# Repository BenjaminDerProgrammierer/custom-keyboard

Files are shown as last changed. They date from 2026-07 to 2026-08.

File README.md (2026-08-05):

# Custom keyboard

My try on a custom keyboard. I've always wanted to design a bigger PCB and case, and Keeb was the perfect opportunity. My challenge is a near-ISO keyboard layout.

## TODO

* what you built, why, and what you learned
* Add Rotary Encoder and OLED display ("Extras")

## Attribution

Thanks to [Hack Club Keeb](https://keeb.hackclub.com/) for encouraging me to build my own keyboard.

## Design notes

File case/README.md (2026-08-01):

# Onshape project export directory

[View my onshape project here](https://cad.onshape.com/documents/79eabb8dc9f468c958f379de/w/43301b686be9b350d744fb77/e/7cf8c5e329865d698f6473ac).

Alternatively, you can use the exported files in this directory.

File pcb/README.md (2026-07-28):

# KiCAD project directory

## Adding gerbers

* Go to File → Fabrication Outputs → Gerbers (.gbr)
* Select all layers (F.Cu, B.Cu, F.Silkscreen, B.Silkscreen, F.Mask, B.Mask, Edge.Cuts) and click Plot
* Then click Generate Drill Files to export the .drl file
* Zip the output folder and commit it alongside your .kicad_pcb and .kicad_sch files

## Layout

For viewing the source layout, upload `layout.json` to <https://www.keyboard-layout-editor.com/>

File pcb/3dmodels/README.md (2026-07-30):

# PCB 3D models

These models are kept with the project so `${KIPRJMOD}` references in
`custom_keyboard.kicad_pcb` do not depend on a particular workstation.

| Project file | Source |
| --- | --- |
| `Cherry_MX.step` | Existing local project asset, formerly referenced as `Cherry MX.STEP` |
| `D_DO-35_SOD27_P7.62mm_Horizontal.step` | [KiCad Packages3D](https://gitlab.com/kicad/libraries/kicad-packages3D/-/raw/master/Diode_THT.3dshapes/D_DO-35_SOD27_P7.62mm_Horizontal.step) |
| `RaspberryPi_Pico.step` | [KiCad Packages3D](https://gitlab.com/kicad/libraries/kicad-packages3D/-/raw/master/Module.3dshapes/RaspberryPi_Pico.step) |
| `Stabilizer-2u.stp` | [Keychron L1 2.25u stabilizer](http://www.keychron.co:34568/keychron-github-assets/Keychron-Keyboards-Hardware-Design/L-Series/L1/Stabilizer-2.25u.stp) |
| `Stabilizer-6.25u.stp` | [Keychron L1 6.25u stabilizer](http://www.keychron.co:34568/keychron-github-assets/Keychron-Keyboards-Hardware-Design/L-Series/L1/Stabilizer-6.25u.stp) |
| `Stabilizer_5u.wrl` | Project-local, footprint-aligned horizontal 5u stabilizer representation |
| `Stabilizer_ISO.wrl` | Project-local, footprint-aligned vertical ISO stabilizer representation |
| `Keycap_1u_Transparent.wrl` | Project-local generic transparent keycap shell |
| `Keycap_ISO_Transparent.wrl` | Project-local transparent ISO Enter shell |

The standard 2.25u stabilizer assembly is also used for the 2u and 2.75u
footprints because they share the same 23.8125 mm stem spacing. ISO Enter uses
a project-local vertical representation aligned directly to its four mounting
holes.

Refer to the upstream projects for their model licensing terms.

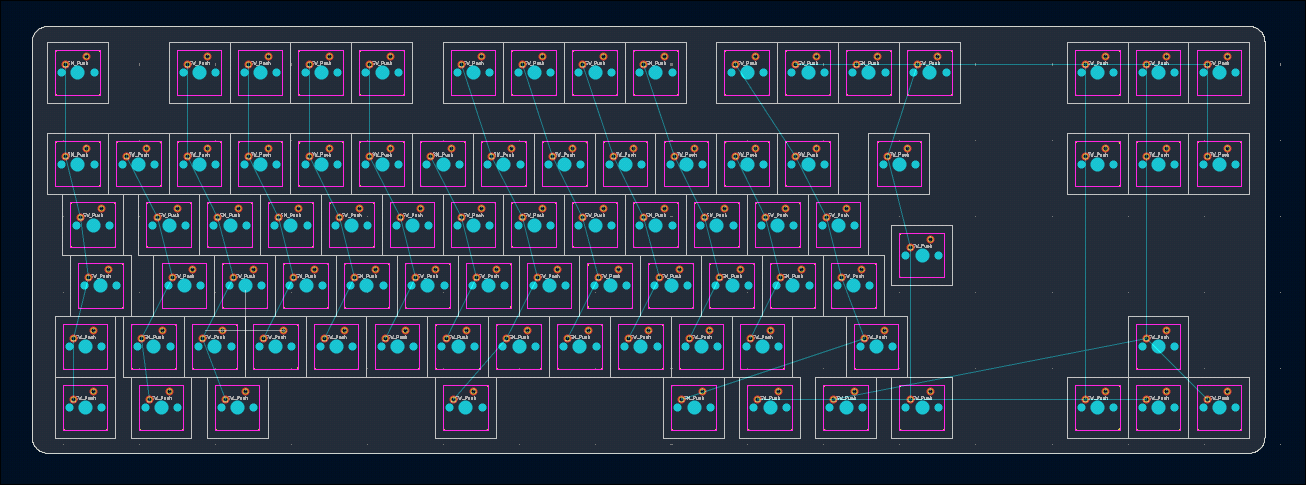
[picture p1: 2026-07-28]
assets/screenshot-003.png

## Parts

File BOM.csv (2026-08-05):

Part | Quantity | PackQuantity | PriceUSD | Link | Notes
Raspberry Pi Pico | 1 | 1 | 9.34 | https://amzn.eu/d/05j1KStX
1N4148 Diode | 87 | 100 | 5.81 | https://amzn.eu/d/0eLkkfi4
EC11 Rotary Encoder | 1 | 10 | 12.33 | https://amzn.eu/d/0akEk5m6
0.91" OLED Display | 1 | 1 | 6.7 | https://amzn.eu/d/095Z39cg
PCB | 1 | 5 | 47.17 |  | JLCPCB see submission/pcb_order.png
MX Switch | 86 | 90 | 51.23 | https://amzn.eu/d/0a2MXvMT
MX Stabilizers | 6 | 8 | 13.07 | https://amzn.eu/d/04WCo8ej
TOTAL |  |  | 145.65

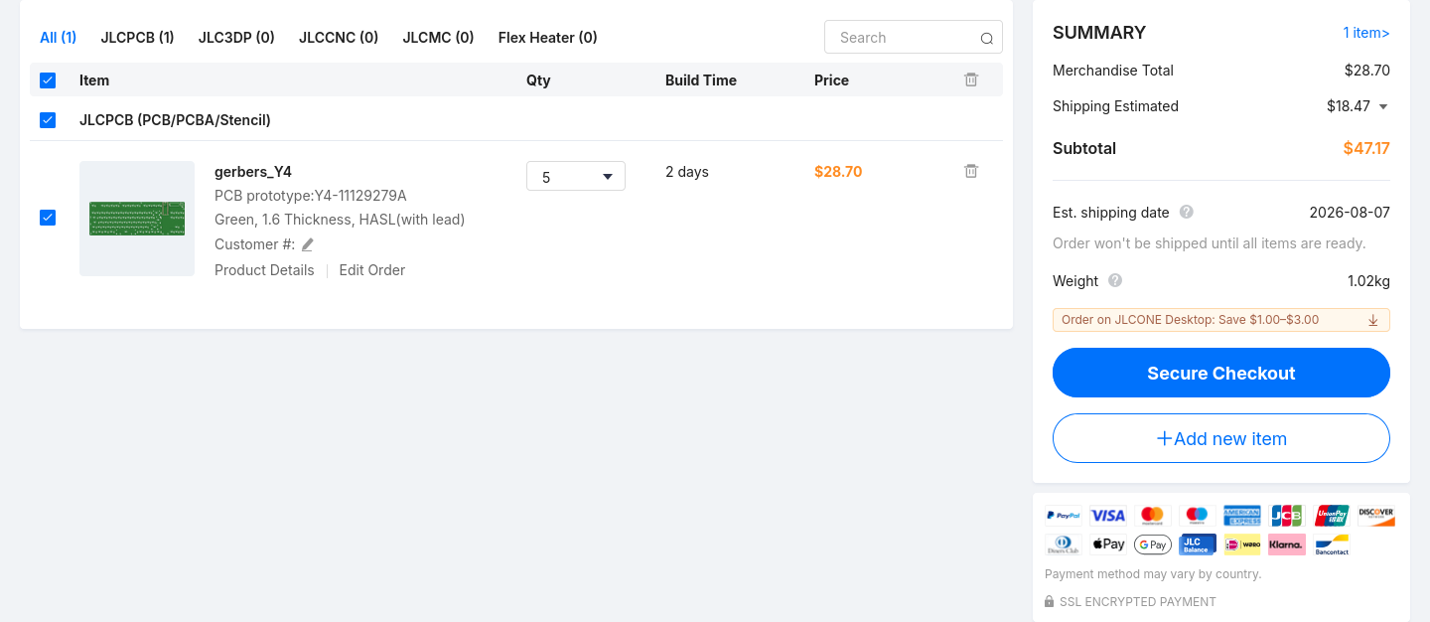
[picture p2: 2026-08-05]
submission/pcb_order.png

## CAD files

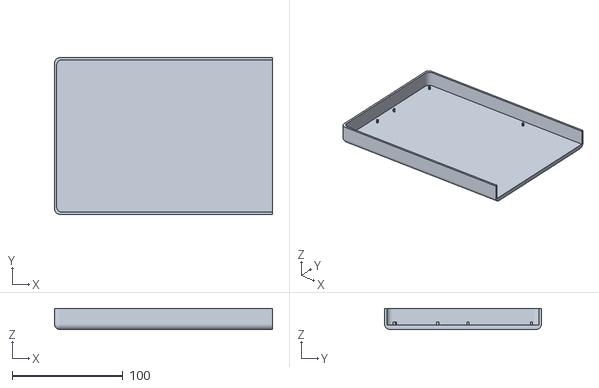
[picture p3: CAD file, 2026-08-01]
case/case - part 1.stl
197.0 x 141.7 x 19.0

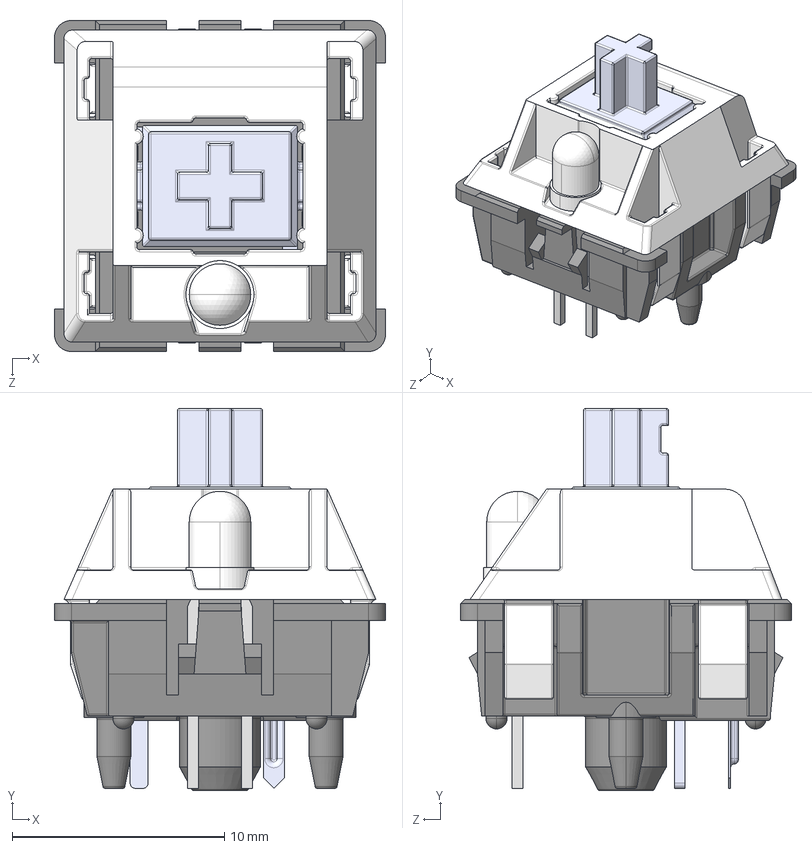
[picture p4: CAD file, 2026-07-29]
pcb/3dmodels/Cherry_MX.step
15.6 x 18.0 x 15.6 mm
Bottom
Pulsador
Top
Pieza5^Cherry MX
Pin1
Pin2
Led 3mm_trans

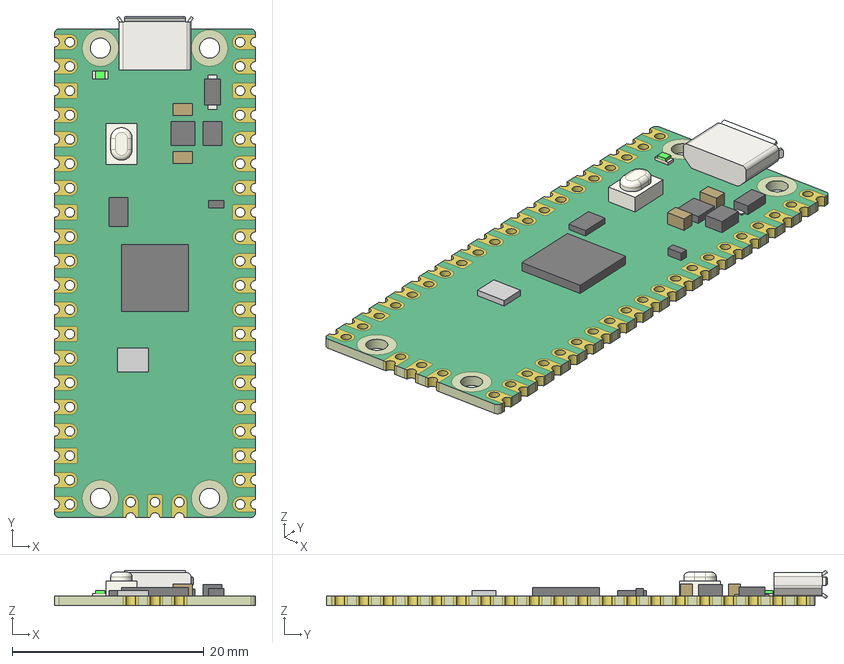
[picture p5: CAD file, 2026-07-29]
pcb/3dmodels/RaspberryPi_Pico.step
21.0 x 52.3 x 3.70 mm

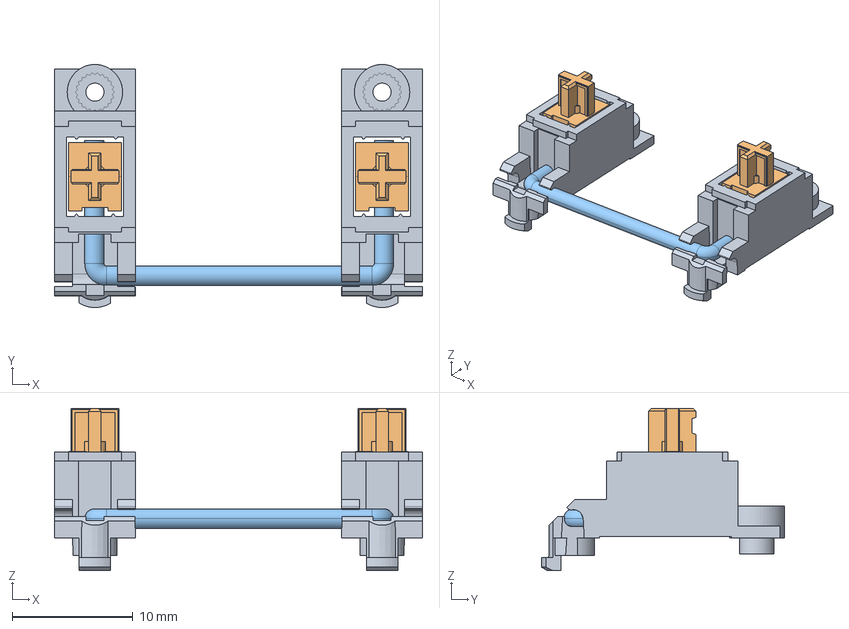
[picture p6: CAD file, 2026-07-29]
pcb/3dmodels/Stabilizer-2u.stp
30.5 x 20.1 x 13.5 mm
WX_Z_4__1_1_25 x 2
D_1_25 x 2
PINGHENGGAN_1_25

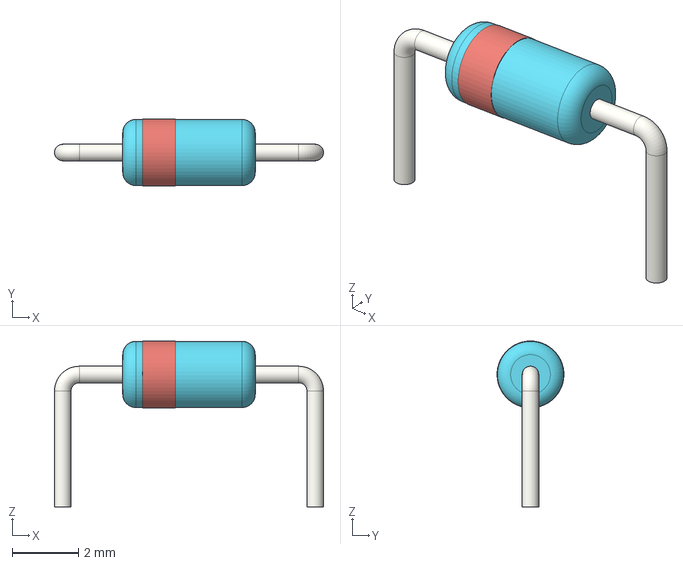
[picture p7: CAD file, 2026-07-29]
pcb/3dmodels/D_DO-35_SOD27_P7.62mm_Horizontal.step
8.12 x 2.02 x 5.01 mm

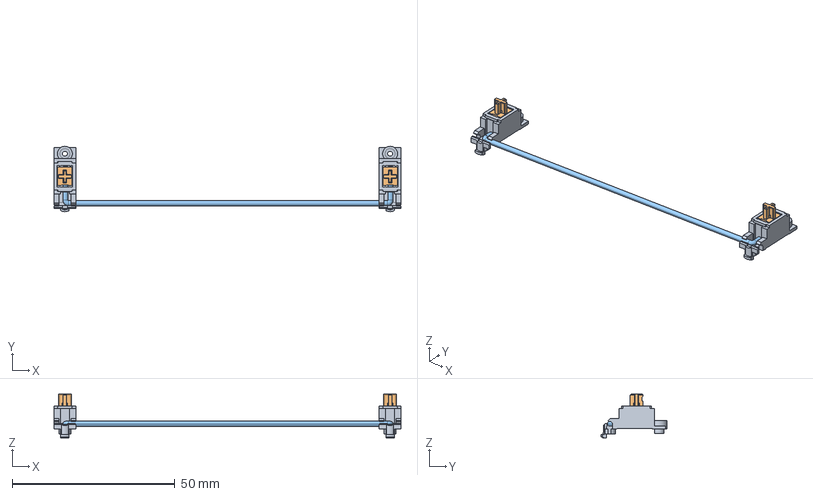
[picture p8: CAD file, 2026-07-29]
pcb/3dmodels/Stabilizer-6.25u.stp
106.7 x 20.1 x 13.5 mm
WX_Z_4__1_1_25 x 2
D_1_25 x 2
PINGHENGGAN100_25

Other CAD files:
case/case - part 2.stl

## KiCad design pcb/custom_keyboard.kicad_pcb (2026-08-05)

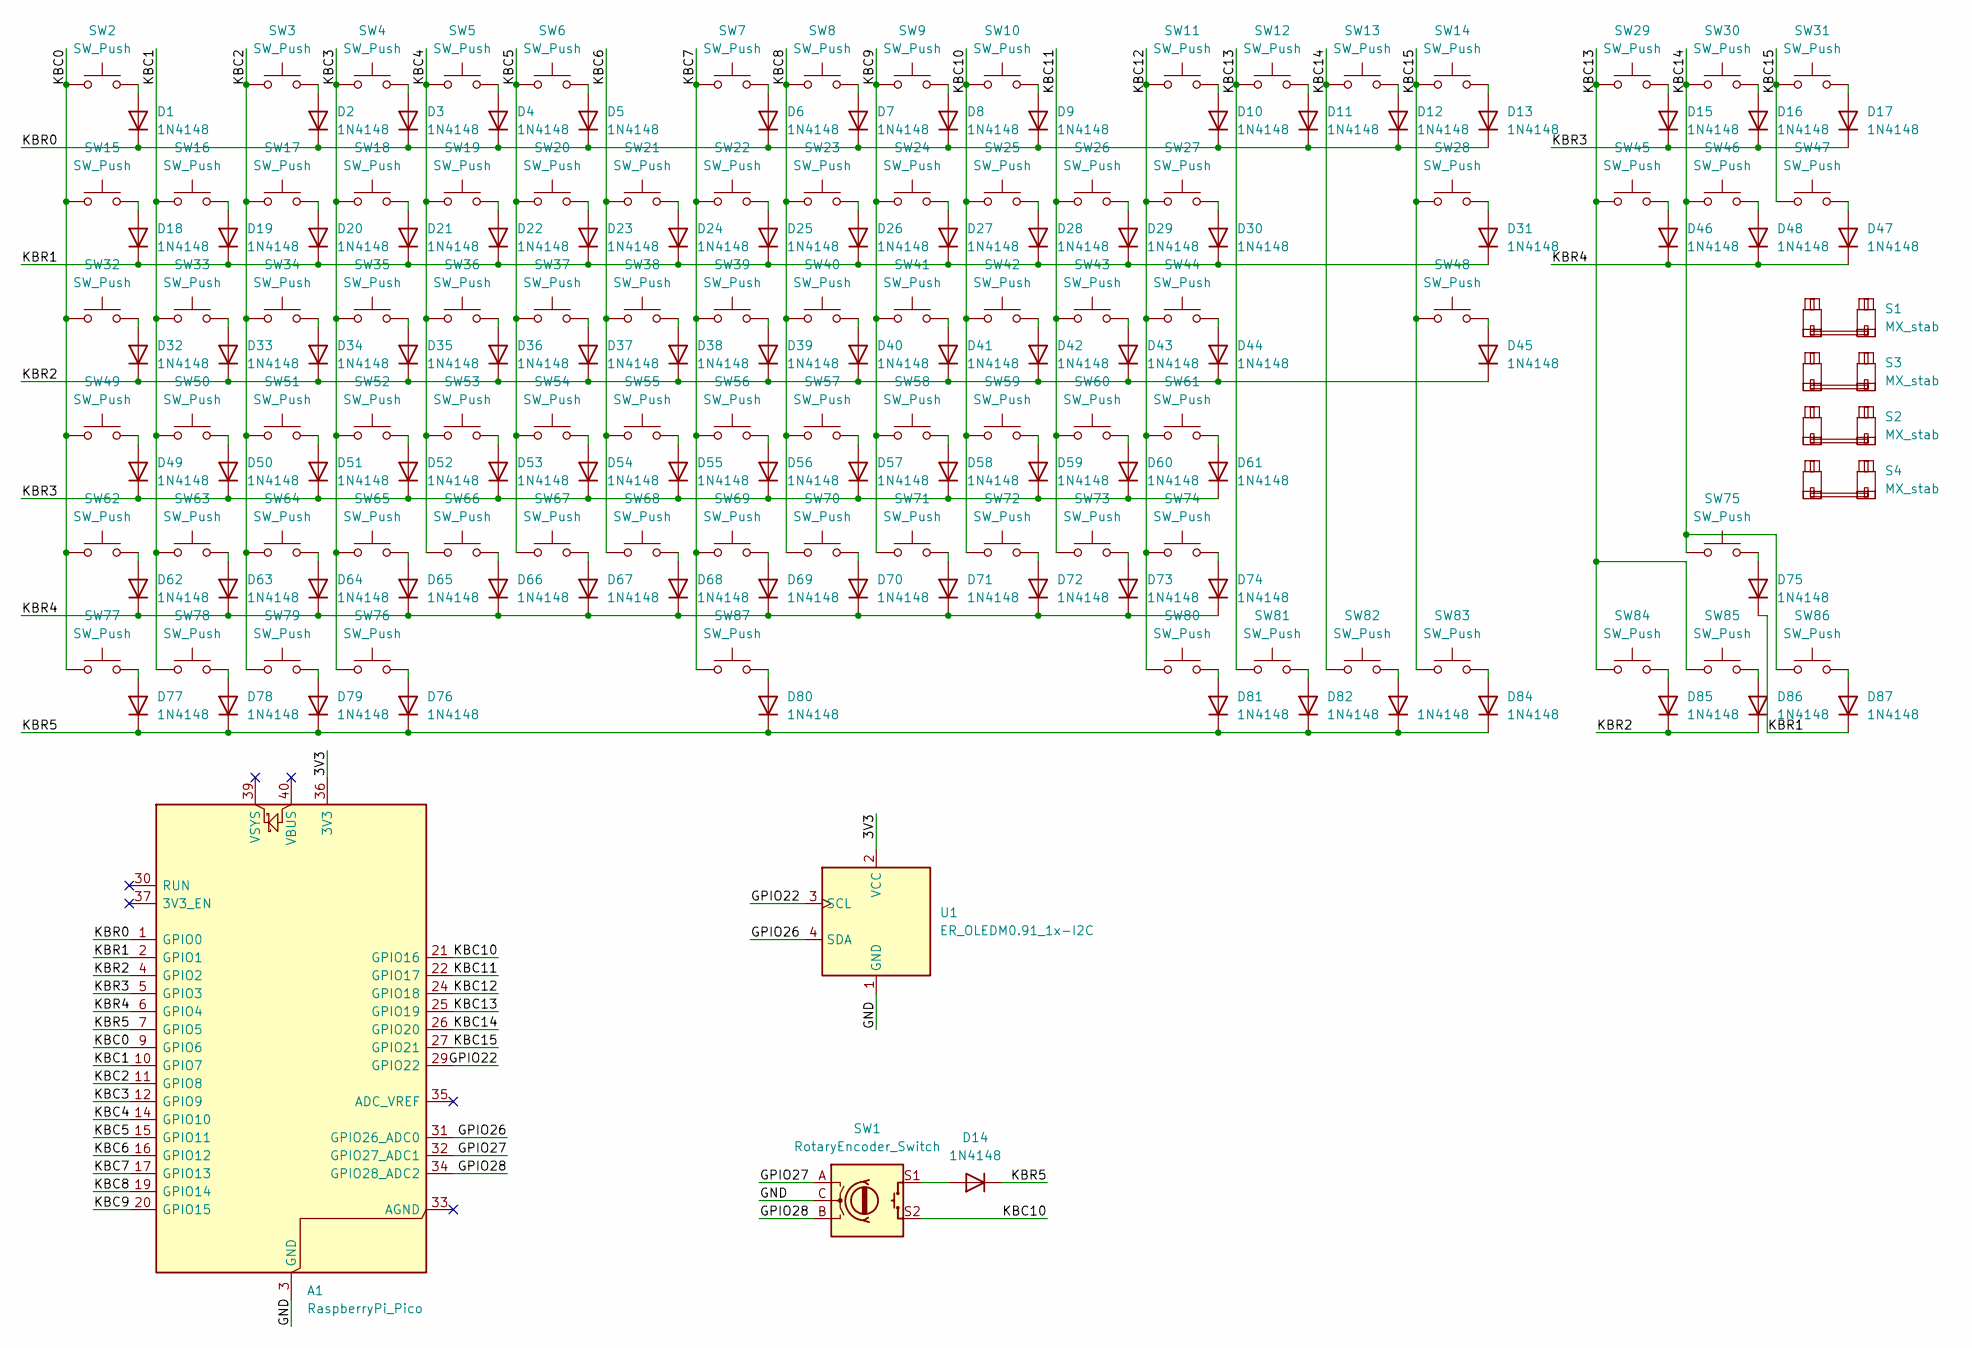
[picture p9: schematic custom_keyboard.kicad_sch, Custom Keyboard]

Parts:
A1: RaspberryPi_Pico; RaspberryPi_Pico_SMD
D1, D2, D3, D4, D5, D6, D7, D8, D9, D10, D11, D12, D13, D14, D15, D16, D17, D18, D19, D20, D21, D22, D23, D24, D25, D26, D27, D28, D29, D30, D31, D32, D33, D34, D35, D36, D37, D38, D39, D40, D41, D42, D43, D44, D45, D46, D47, D48, D49, D50, D51, D52, D53, D54, D55, D56, D57, D58, D59, D60, D61, D62, D63, D64, D65, D66, D67, D68, D69, D70, D71, D72, D73, D74, D75, D76, D77, D78, D79, D80, D81, D82, D83, D84, D85, D86, D87: 1N4148; D_DO-35_SOD27_P7.62mm_Horizontal
S1: MX_stab; STAB_MX_2u
S2: MX_stab; STAB_MX_ISO
S3: MX_stab; STAB_MX_2.75u
S4: MX_stab; STAB_MX_5u
SW1: RotaryEncoder_Switch; RotaryEncoder_Alps_EC11E-Switch_Vertical_H20mm
SW2, SW3, SW4, SW5, SW6, SW7, SW8, SW9, SW10, SW11, SW12, SW13, SW14, SW15, SW16, SW17, SW18, SW19, SW20, SW21, SW22, SW23, SW24, SW25, SW26, SW27, SW28, SW29, SW30, SW31, SW33, SW34, SW35, SW36, SW37, SW38, SW39, SW40, SW41, SW42, SW43, SW44, SW45, SW46, SW47, SW48, SW50, SW51, SW52, SW53, SW54, SW55, SW56, SW57, SW58, SW59, SW60, SW61, SW63, SW64, SW65, SW66, SW67, SW68, SW69, SW70, SW71, SW72, SW73, SW74, SW75, SW84, SW85, SW86, SW87: SW_Push; SW_MX_1u
SW32: SW_Push; SW_MX_1.5u
SW49: SW_Push; SW_MX_1.75u
SW62, SW76, SW77, SW78, SW79, SW80, SW81, SW82, SW83: SW_Push; SW_MX_1.25u
U1: ER_OLEDM0.91_1x-I2C

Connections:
/3V3: A1.36 (3V3), U1.2 (VCC)
/GND: A1.3 (GND), A1.8 (GND), A1.13 (GND), A1.18 (GND), A1.23 (GND), A1.28 (GND), A1.38 (GND), SW1.C, U1.1 (GND)
/GPIO22: A1.29 (GPIO22), U1.3 (SCL)
/GPIO26: A1.31 (GPIO26_ADC0), U1.4 (SDA)
/GPIO27: A1.32 (GPIO27_ADC1), SW1.A
/GPIO28: A1.34 (GPIO28_ADC2), SW1.B
/KBC0: A1.9 (GPIO6), SW2.1, SW15.1, SW32.1, SW49.1, SW62.1, SW77.1
/KBC1: A1.10 (GPIO7), SW16.1, SW33.1, SW50.1, SW63.1, SW78.1
/KBC2: A1.11 (GPIO8), SW3.1, SW17.1, SW34.1, SW51.1, SW64.1, SW79.1
/KBC3: A1.12 (GPIO9), SW4.1, SW18.1, SW35.1, SW52.1, SW65.1, SW76.1
/KBC4: A1.14 (GPIO10), SW5.1, SW19.1, SW36.1, SW53.1, SW66.1
/KBC5: A1.15 (GPIO11), SW6.1, SW20.1, SW37.1, SW54.1, SW67.1
/KBC6: A1.16 (GPIO12), SW21.1, SW38.1, SW55.1, SW68.1
/KBC7: A1.17 (GPIO13), SW7.1, SW22.1, SW39.1, SW56.1, SW69.1, SW87.1
/KBC8: A1.19 (GPIO14), SW8.1, SW23.1, SW40.1, SW57.1, SW70.1
/KBC9: A1.20 (GPIO15), SW9.1, SW24.1, SW41.1, SW58.1, SW71.1
/KBC10: A1.21 (GPIO16), SW1.S2, SW10.1, SW25.1, SW42.1, SW59.1, SW72.1
/KBC11: A1.22 (GPIO17), SW26.1, SW43.1, SW60.1, SW73.1
/KBC12: A1.24 (GPIO18), SW11.1, SW27.1, SW44.1, SW61.1, SW74.1, SW80.1
/KBC13: A1.25 (GPIO19), SW12.1, SW29.1, SW45.1, SW81.1, SW84.1, SW85.1
/KBC14: A1.26 (GPIO20), SW13.1, SW30.1, SW46.1, SW75.1, SW82.1, SW86.1
/KBC15: A1.27 (GPIO21), SW14.1, SW28.1, SW31.1, SW47.1, SW48.1, SW83.1
/KBR0: A1.1 (GPIO0), D1.1 (K), D2.1 (K), D3.1 (K), D4.1 (K), D5.1 (K), D6.1 (K), D7.1 (K), D8.1 (K), D9.1 (K), D10.1 (K), D11.1 (K), D12.1 (K), D13.1 (K)
/KBR1: A1.2 (GPIO1), D18.1 (K), D19.1 (K), D20.1 (K), D21.1 (K), D22.1 (K), D23.1 (K), D24.1 (K), D25.1 (K), D26.1 (K), D27.1 (K), D28.1 (K), D29.1 (K), D30.1 (K), D31.1 (K), D75.1 (K), D87.1 (K)
/KBR2: A1.4 (GPIO2), D32.1 (K), D33.1 (K), D34.1 (K), D35.1 (K), D36.1 (K), D37.1 (K), D38.1 (K), D39.1 (K), D40.1 (K), D41.1 (K), D42.1 (K), D43.1 (K), D44.1 (K), D45.1 (K), D85.1 (K), D86.1 (K)
/KBR3: A1.5 (GPIO3), D15.1 (K), D16.1 (K), D17.1 (K), D49.1 (K), D50.1 (K), D51.1 (K), D52.1 (K), D53.1 (K), D54.1 (K), D55.1 (K), D56.1 (K), D57.1 (K), D58.1 (K), D59.1 (K), D60.1 (K), D61.1 (K)
/KBR4: A1.6 (GPIO4), D46.1 (K), D47.1 (K), D48.1 (K), D62.1 (K), D63.1 (K), D64.1 (K), D65.1 (K), D66.1 (K), D67.1 (K), D68.1 (K), D69.1 (K), D70.1 (K), D71.1 (K), D72.1 (K), D73.1 (K), D74.1 (K)
/KBR5: A1.7 (GPIO5), D14.1 (K), D76.1 (K), D77.1 (K), D78.1 (K), D79.1 (K), D80.1 (K), D81.1 (K), D82.1 (K), D83.1 (K), D84.1 (K)
unnamed: D1.2 (A), SW2.2
unnamed: D2.2 (A), SW3.2
unnamed: D3.2 (A), SW4.2
unnamed: D4.2 (A), SW5.2
unnamed: D5.2 (A), SW6.2
unnamed: D6.2 (A), SW7.2
unnamed: D7.2 (A), SW8.2
unnamed: D8.2 (A), SW9.2
unnamed: D9.2 (A), SW10.2
unnamed: D10.2 (A), SW11.2
unnamed: D11.2 (A), SW12.2
unnamed: D12.2 (A), SW13.2
unnamed: D13.2 (A), SW14.2
unnamed: D14.2 (A), SW1.S1
unnamed: D15.2 (A), SW29.2
unnamed: D16.2 (A), SW30.2
unnamed: D17.2 (A), SW31.2
unnamed: D18.2 (A), SW15.2
unnamed: D19.2 (A), SW16.2
unnamed: D20.2 (A), SW17.2
unnamed: D21.2 (A), SW18.2
unnamed: D22.2 (A), SW19.2
unnamed: D23.2 (A), SW20.2
unnamed: D24.2 (A), SW21.2
unnamed: D25.2 (A), SW22.2
unnamed: D26.2 (A), SW23.2
unnamed: D27.2 (A), SW24.2
unnamed: D28.2 (A), SW25.2
unnamed: D29.2 (A), SW26.2
unnamed: D30.2 (A), SW27.2
unnamed: D31.2 (A), SW28.2
unnamed: D32.2 (A), SW32.2
unnamed: D33.2 (A), SW33.2
unnamed: D34.2 (A), SW34.2
unnamed: D35.2 (A), SW35.2
unnamed: D36.2 (A), SW36.2
unnamed: D37.2 (A), SW37.2
unnamed: D38.2 (A), SW38.2
unnamed: D39.2 (A), SW39.2
unnamed: D40.2 (A), SW40.2
unnamed: D41.2 (A), SW41.2
unnamed: D42.2 (A), SW42.2
unnamed: D43.2 (A), SW43.2
unnamed: D44.2 (A), SW44.2
unnamed: D45.2 (A), SW48.2
unnamed: D46.2 (A), SW45.2
unnamed: D47.2 (A), SW47.2
unnamed: D48.2 (A), SW46.2
unnamed: D49.2 (A), SW49.2
unnamed: D50.2 (A), SW50.2
unnamed: D51.2 (A), SW51.2
unnamed: D52.2 (A), SW52.2
unnamed: D53.2 (A), SW53.2
unnamed: D54.2 (A), SW54.2
unnamed: D55.2 (A), SW55.2
unnamed: D56.2 (A), SW56.2
unnamed: D57.2 (A), SW57.2
unnamed: D58.2 (A), SW58.2
unnamed: D59.2 (A), SW59.2
unnamed: D60.2 (A), SW60.2
unnamed: D61.2 (A), SW61.2
unnamed: D62.2 (A), SW62.2
unnamed: D63.2 (A), SW63.2
unnamed: D64.2 (A), SW64.2
unnamed: D65.2 (A), SW65.2
unnamed: D66.2 (A), SW66.2
unnamed: D67.2 (A), SW67.2
unnamed: D68.2 (A), SW68.2
unnamed: D69.2 (A), SW69.2
unnamed: D70.2 (A), SW70.2
unnamed: D71.2 (A), SW71.2
unnamed: D72.2 (A), SW72.2
unnamed: D73.2 (A), SW73.2
unnamed: D74.2 (A), SW74.2
unnamed: D75.2 (A), SW75.2
unnamed: D76.2 (A), SW76.2
unnamed: D77.2 (A), SW77.2
unnamed: D78.2 (A), SW78.2
unnamed: D79.2 (A), SW79.2
unnamed: D80.2 (A), SW87.2
unnamed: D81.2 (A), SW80.2
unnamed: D82.2 (A), SW81.2
unnamed: D83.2 (A), SW82.2
unnamed: D84.2 (A), SW83.2
unnamed: D85.2 (A), SW84.2
unnamed: D86.2 (A), SW85.2
unnamed: D87.2 (A), SW86.2

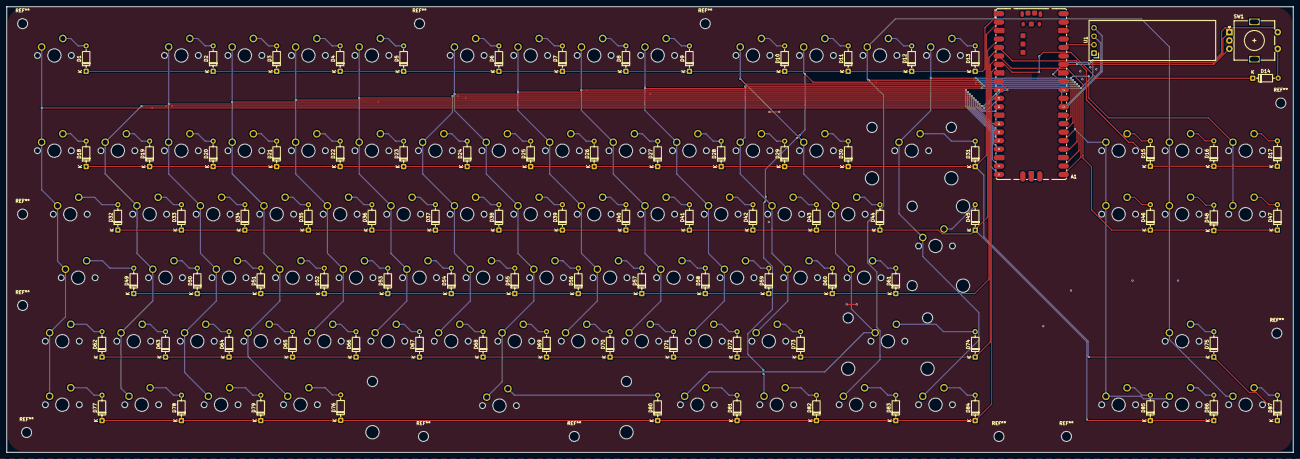
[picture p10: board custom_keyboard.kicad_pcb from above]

Board: 2 copper layers, 385.9 x 133.7 mm, 180 parts (0 on the bottom side), 115 nets.

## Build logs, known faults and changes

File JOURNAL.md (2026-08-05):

# Custom keyboard - Journal

## 2026-07-27: Starting the project

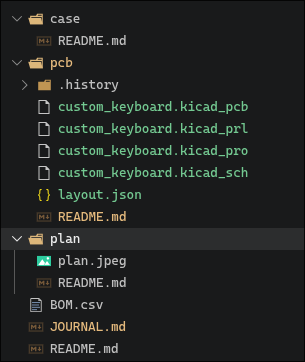
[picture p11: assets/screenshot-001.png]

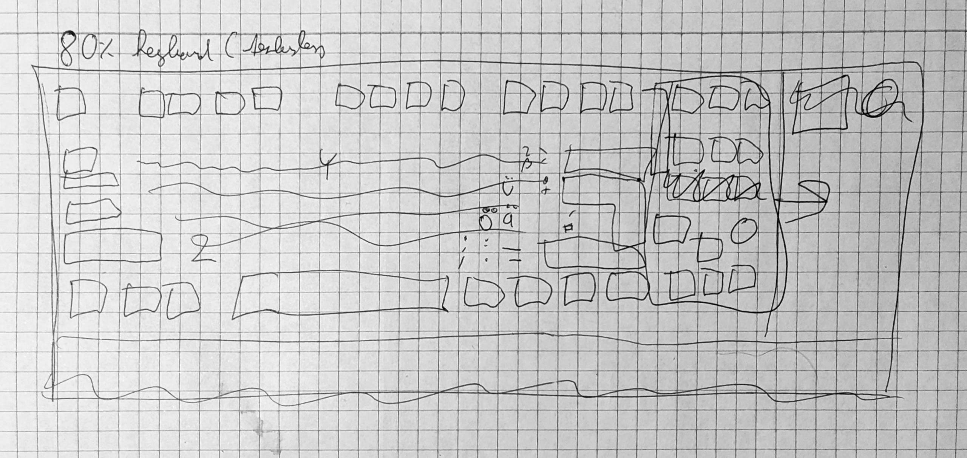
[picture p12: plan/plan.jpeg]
Plan

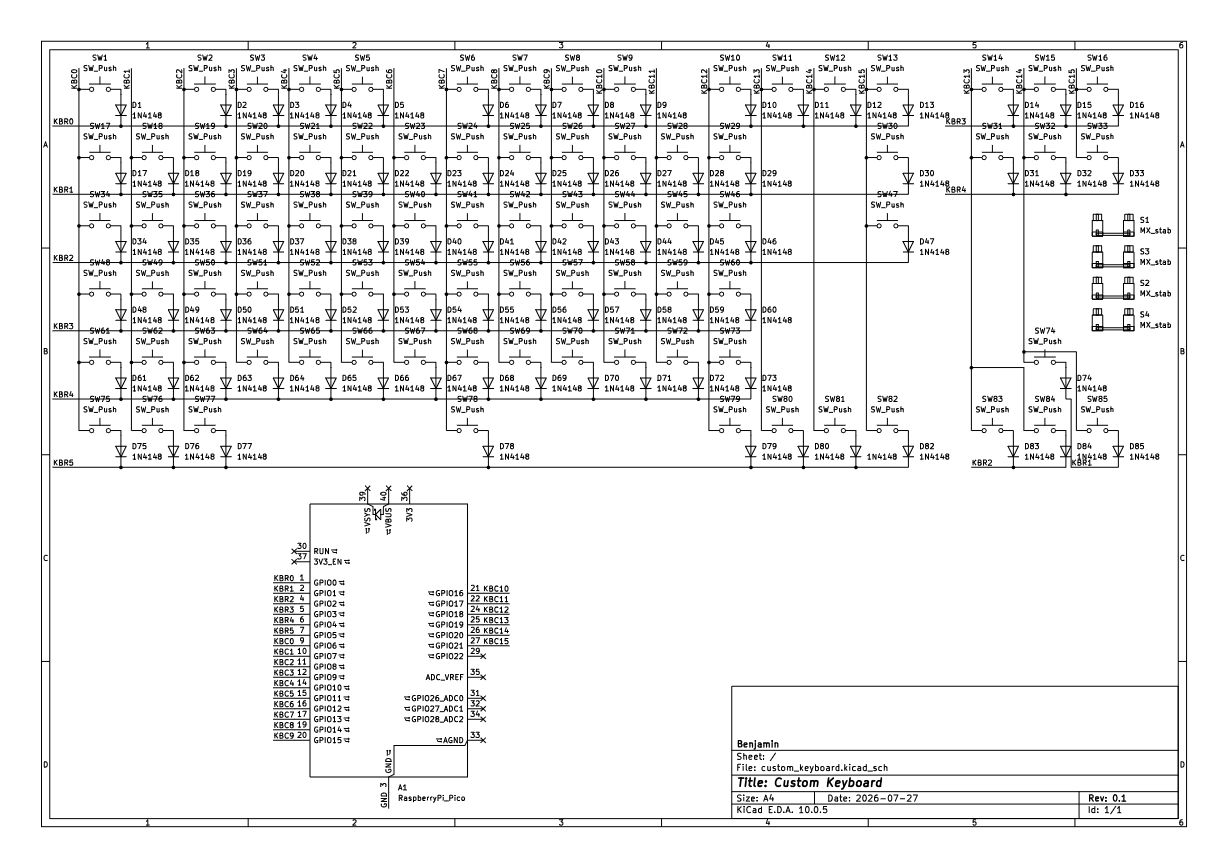
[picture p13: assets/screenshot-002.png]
Schematic

PCB - all keys placed

* Set up GitHub repository, add README.md and JOURNAL.md files, add filder structure, initialize KiCad project (~10m)
* Plan my Keyboard design (~5m)
* Design the schematic (~1h 5m)
* Start placing components on PCB (~20m)

## 2026-07-28: PCB design

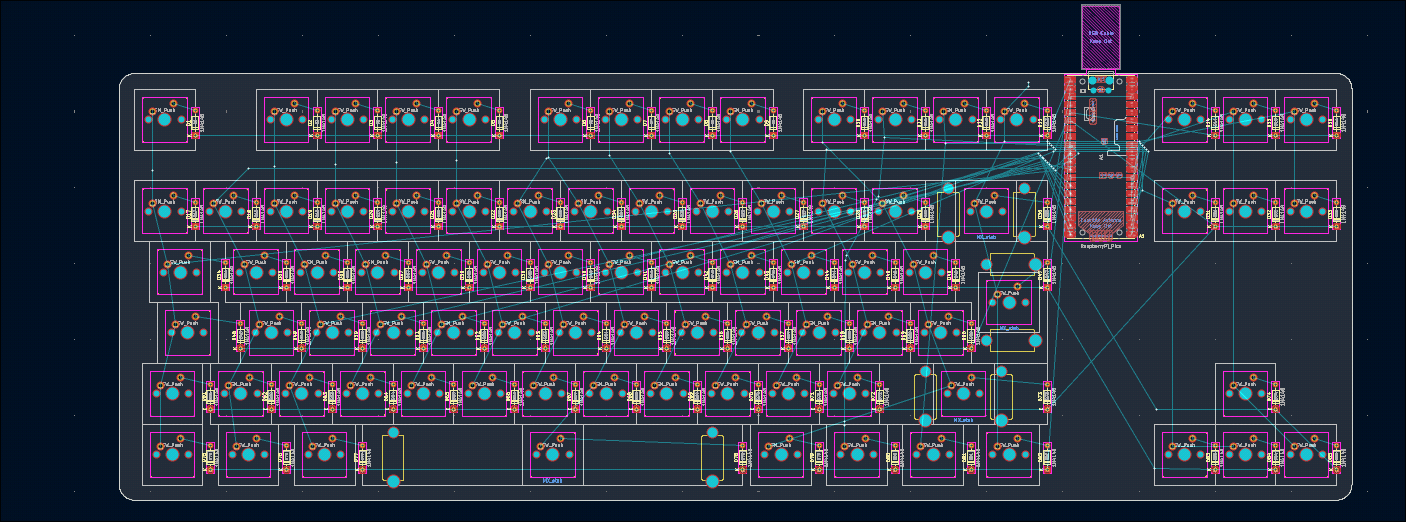
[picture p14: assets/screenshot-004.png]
PCB - all components placed

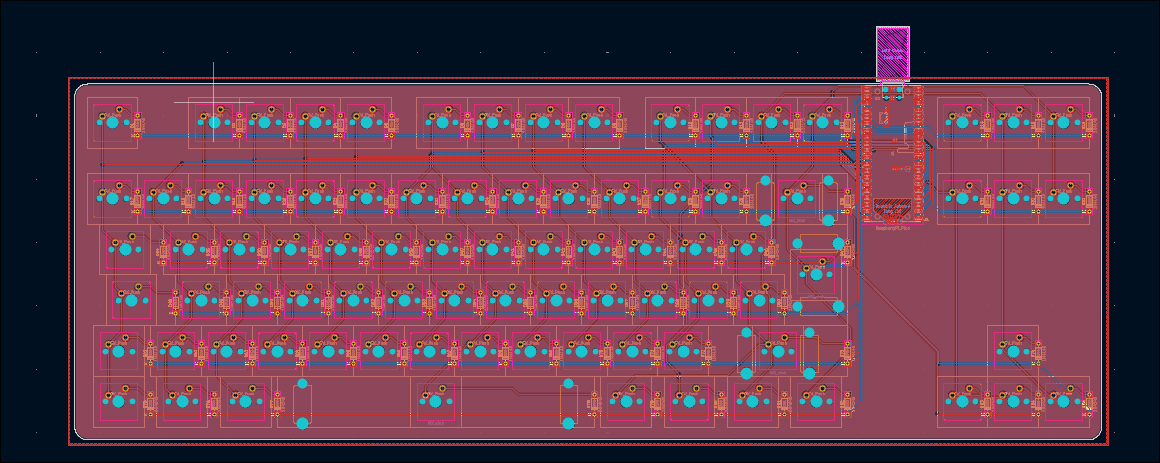
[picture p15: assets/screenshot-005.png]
PCB - finished routing


* Continue placing components on PCB (~2h)
* Route the PCB (~1h 30m)

## 2026-07-29: PCB design

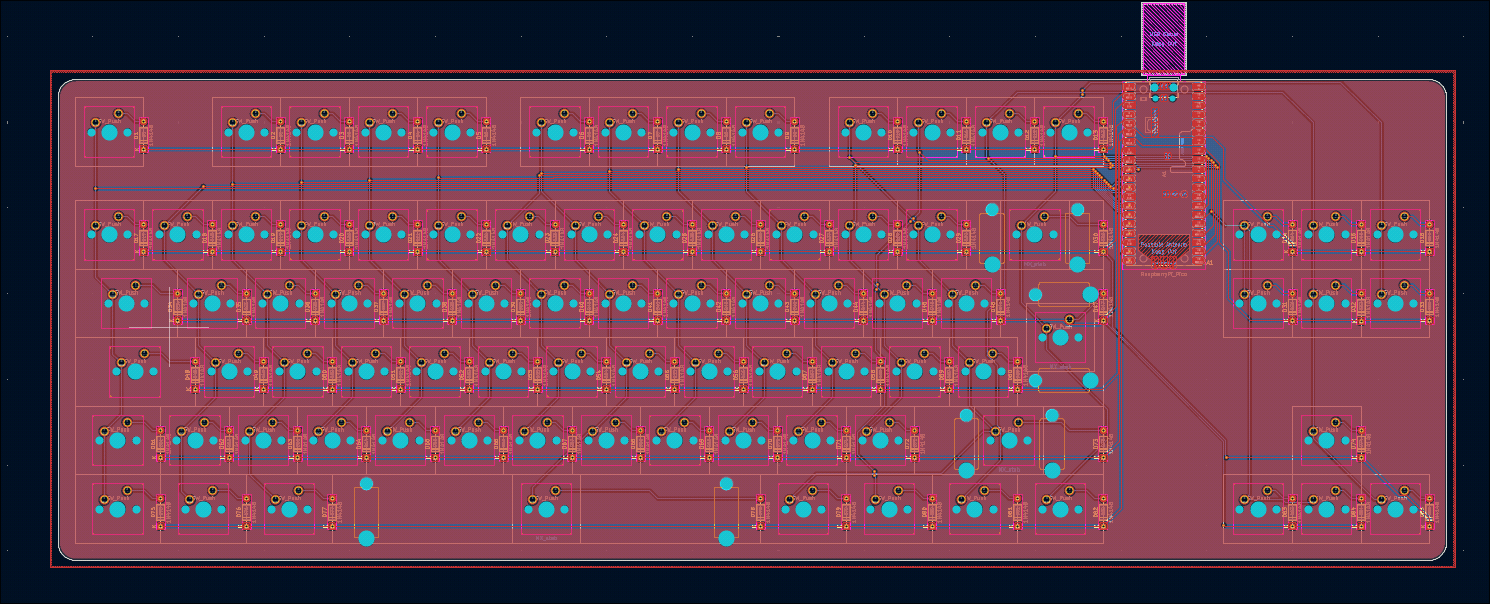
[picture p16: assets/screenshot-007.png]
PCB - all components fixed

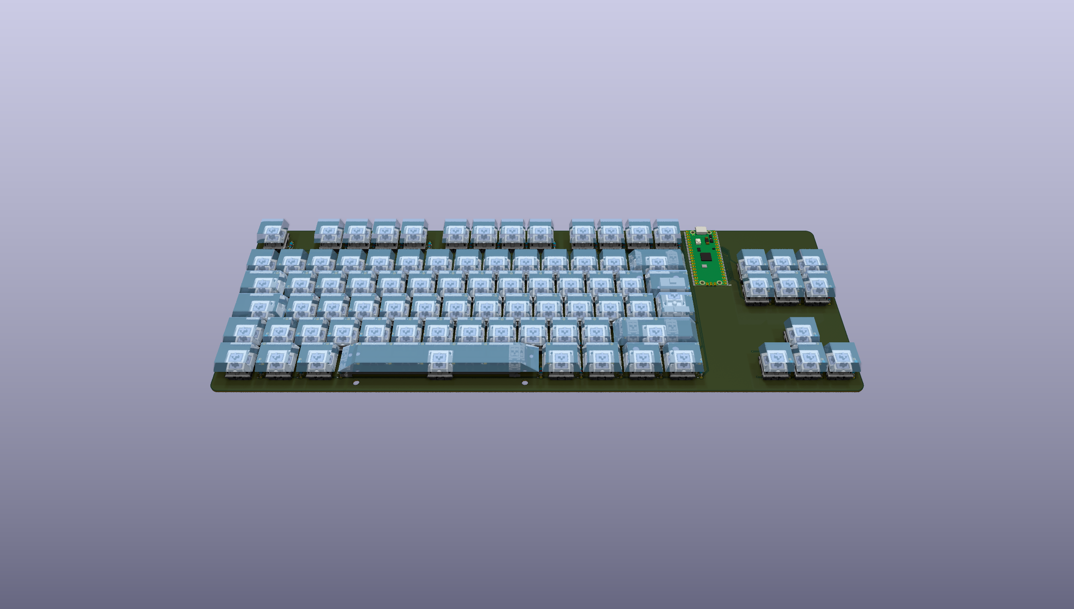
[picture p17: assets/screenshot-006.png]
PCB - 3d render


* Fix footprints, add 3d models (~30m)
* Export gerbers and BOM (~5m)

## 2026-07-29: Custom components

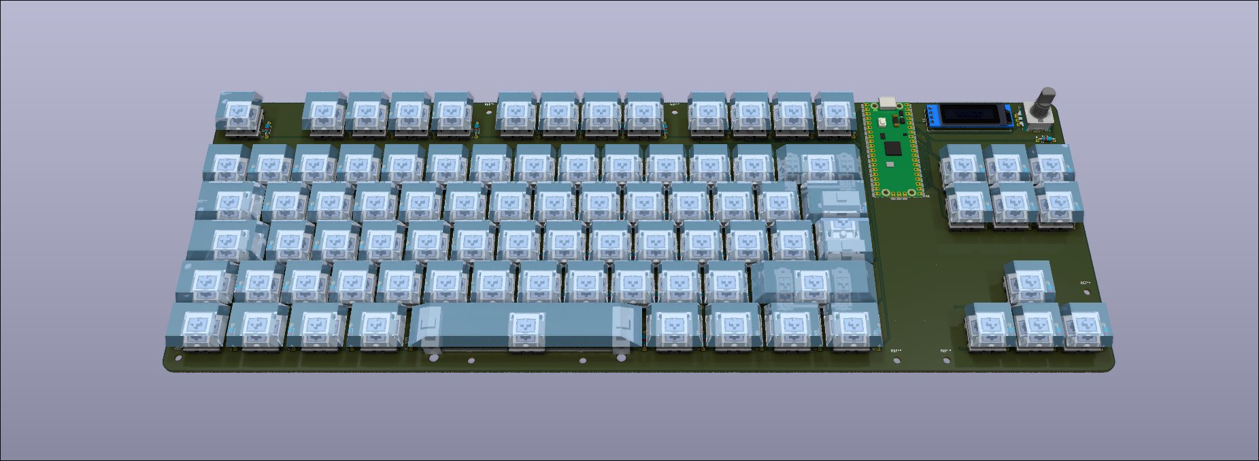
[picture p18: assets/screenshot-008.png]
PCB with mounting holes and custom components


* add OLED display, Rotary Encoder, and fn key (~1h 30m)
* add mounting holes (~30m)

## 2026-07-31: Design Case

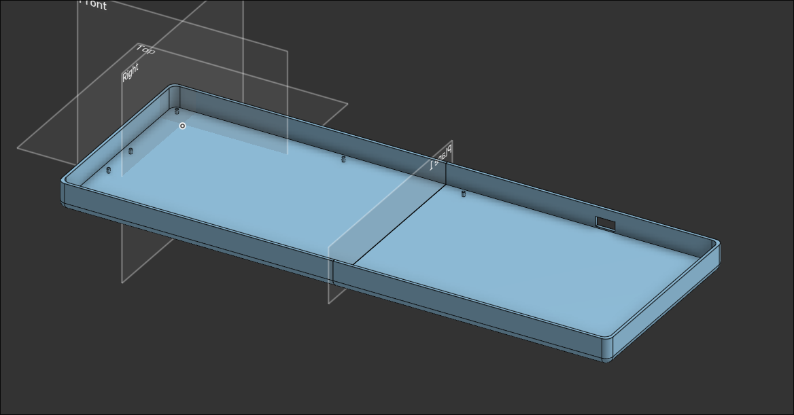
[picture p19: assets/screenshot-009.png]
Case Design in Onshape

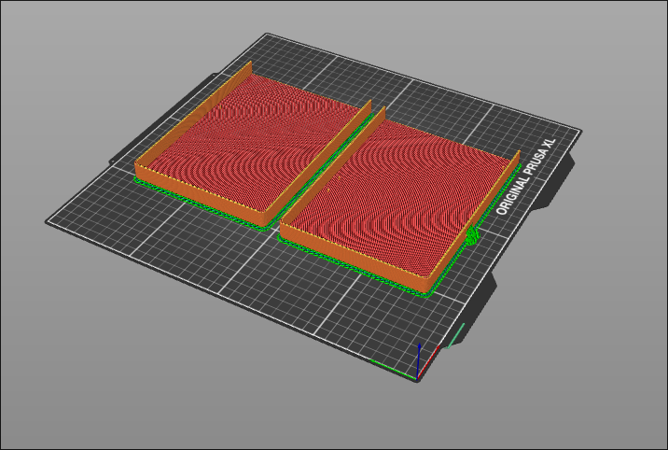
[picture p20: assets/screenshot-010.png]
Sliced Case


* Design the case for the keyboard (~1h 30m)

## 2026-08-05: BOM and Submission

* Finalize BOM, and submit the project for a grant (~1h)

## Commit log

2026-07-28 Add progress from 2026-07-27 and 2026-07-28
    [custom_keyboard.kicad_pcb, custom_keyboard.kicad_sch]
2026-07-29 Add progress from today
    [BOM.csv, Cherry_MX.step, D_DO-35_SOD27_P7.62mm_Horizontal.step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]
2026-07-30 Add mounting holes and custom components
    [custom_keyboard.kicad_pcb, custom_keyboard.kicad_sch]
2026-08-01 Add custom components and design case
    [BOM.csv, case - part 1.stl, case - part 2.stl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]
